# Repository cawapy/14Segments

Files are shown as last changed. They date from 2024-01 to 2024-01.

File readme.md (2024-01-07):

# Gallery

## Plain PCB

### Front

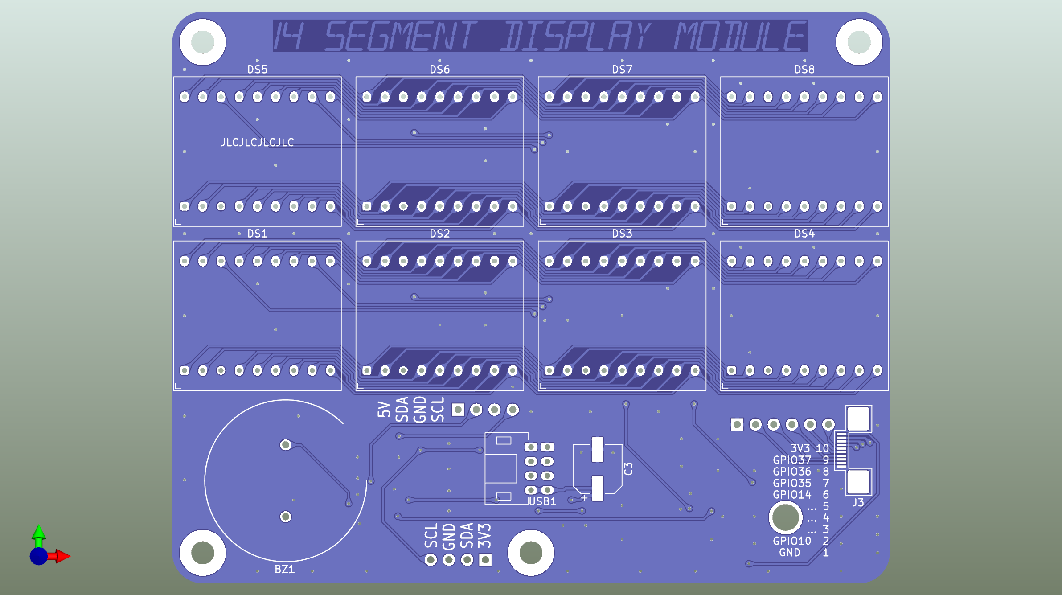
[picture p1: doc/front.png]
Front


### Back

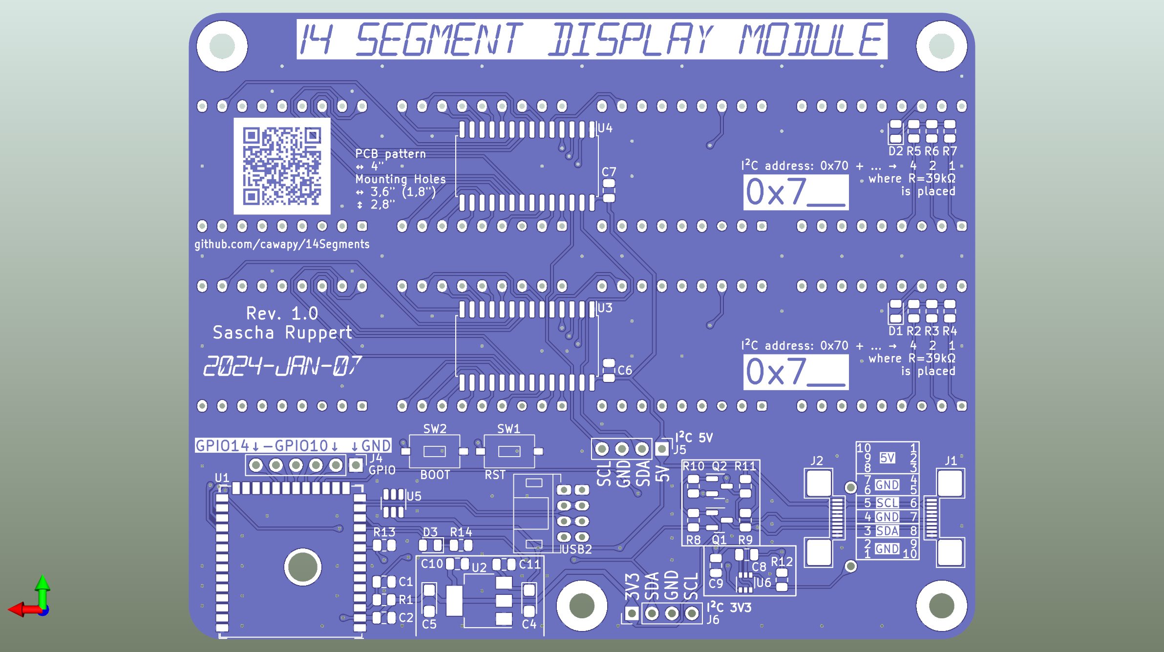
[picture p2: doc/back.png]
Back


## Master Board Assembly

### Front

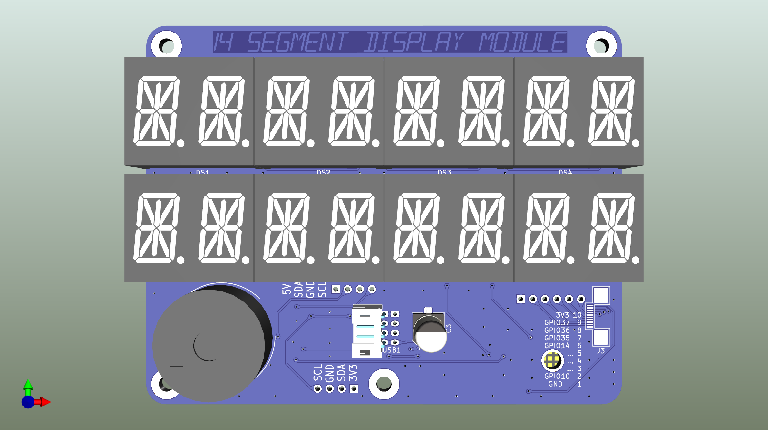
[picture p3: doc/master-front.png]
Front

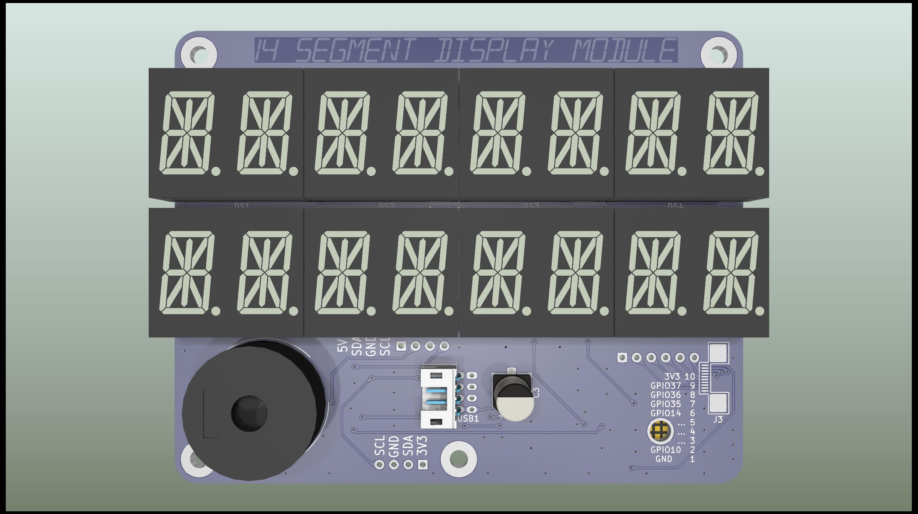
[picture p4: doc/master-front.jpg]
Front


### Back

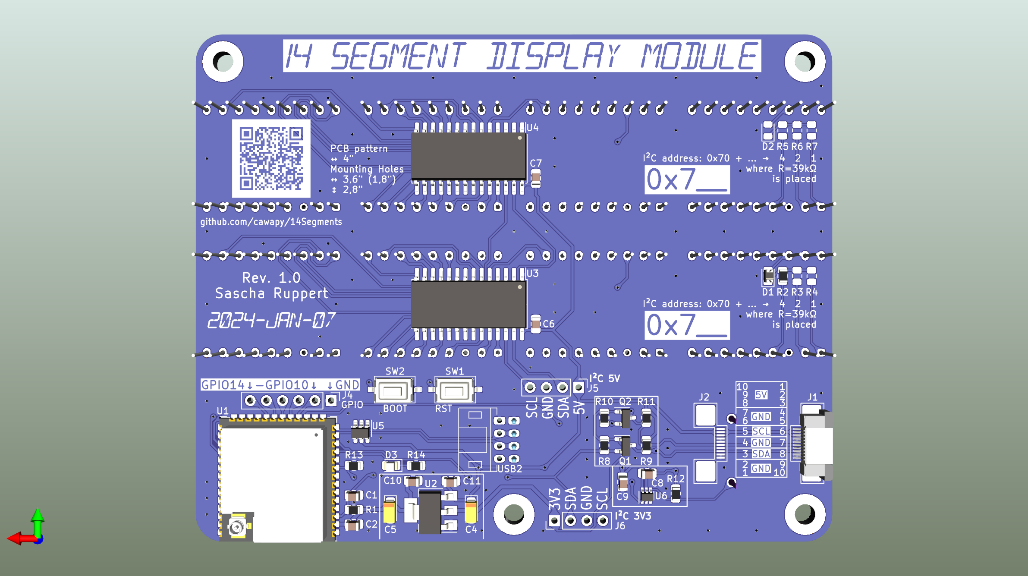
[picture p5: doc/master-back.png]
Back

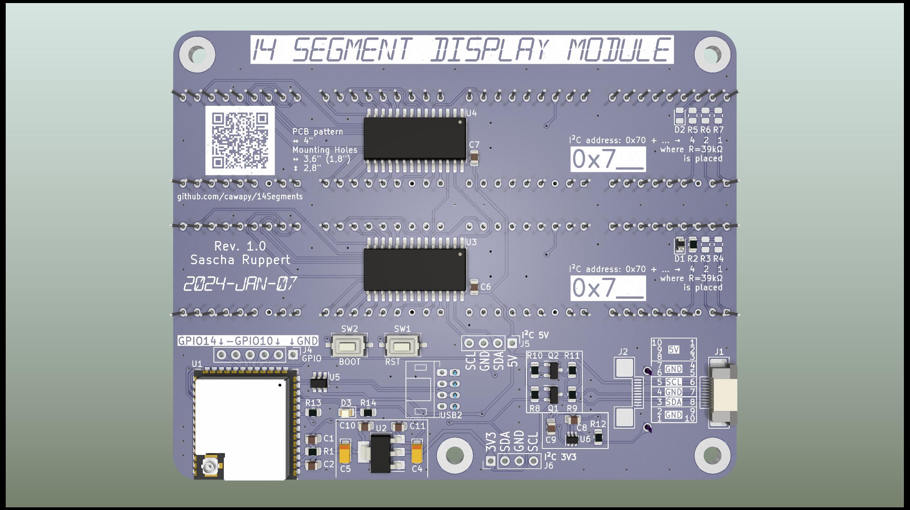
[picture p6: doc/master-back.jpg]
Back


## Slave Board Assembly

### Front

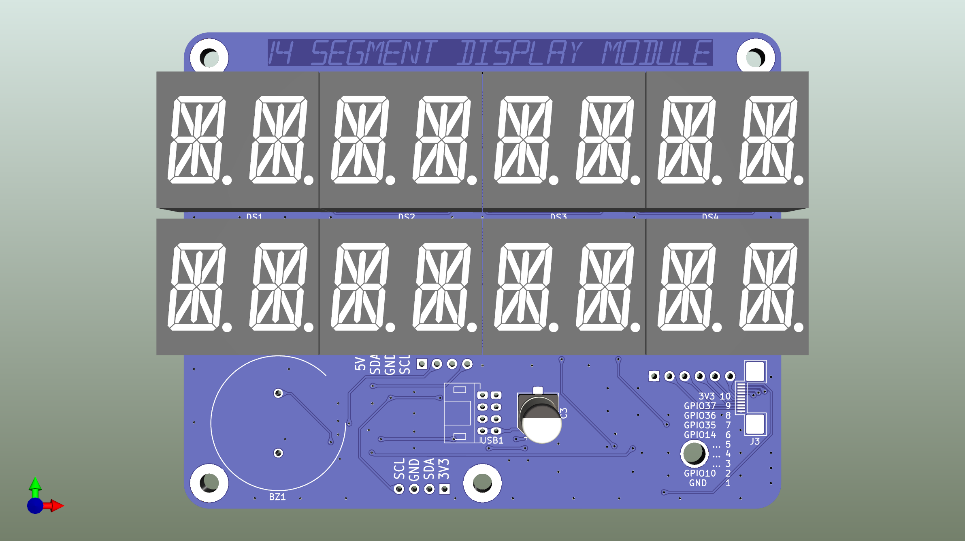
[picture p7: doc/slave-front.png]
Front

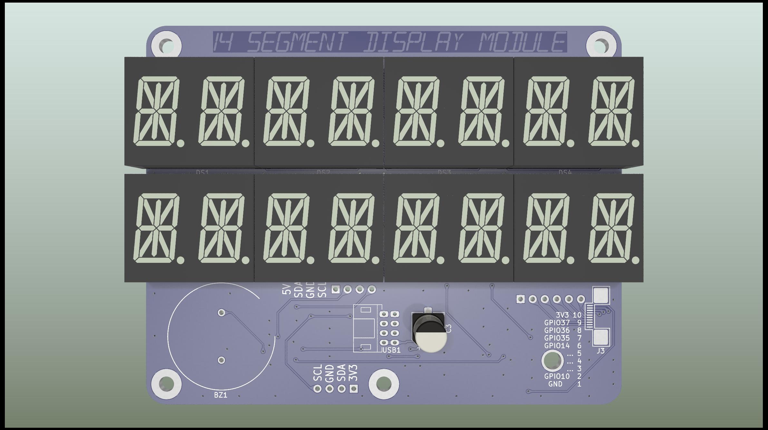
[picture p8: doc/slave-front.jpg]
Front


### Back

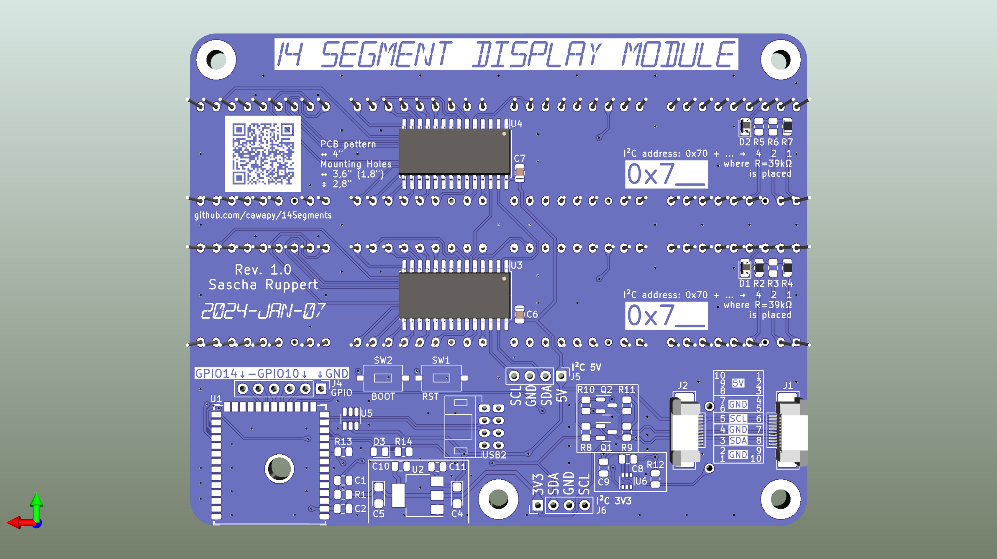
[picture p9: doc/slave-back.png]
Back

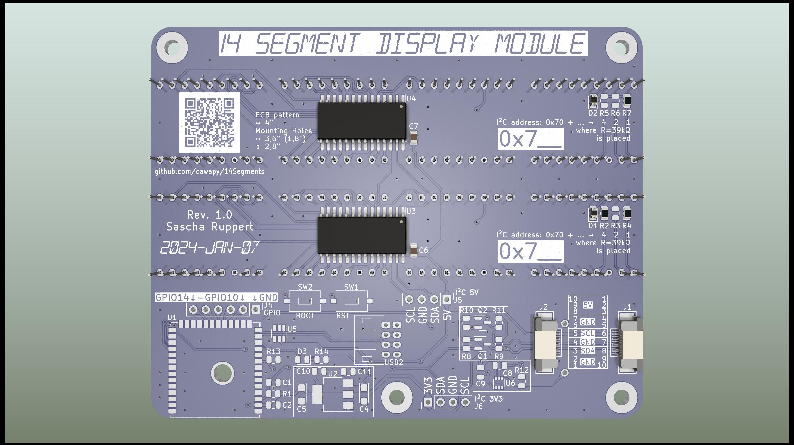
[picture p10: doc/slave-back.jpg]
Back


## Master + Slave Configuration

### Front

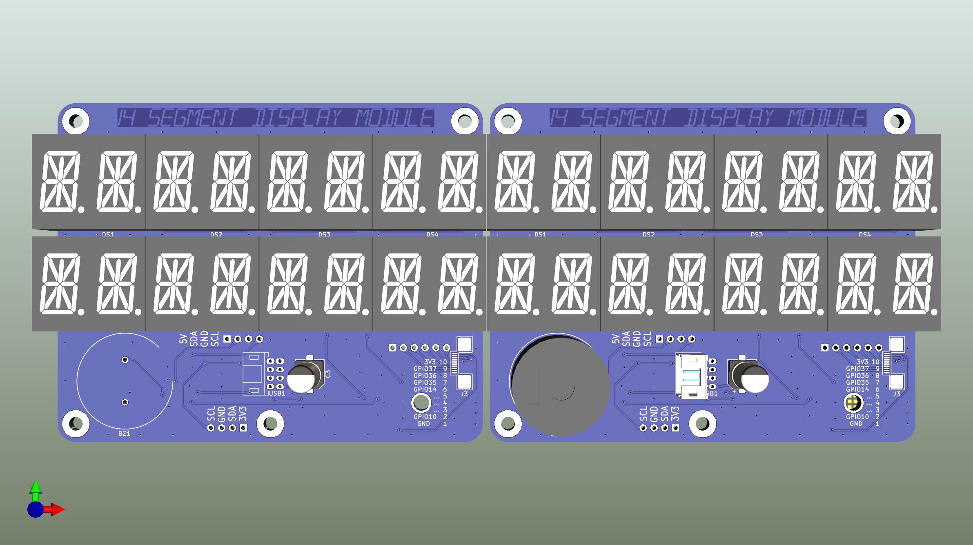
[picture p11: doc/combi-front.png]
Front

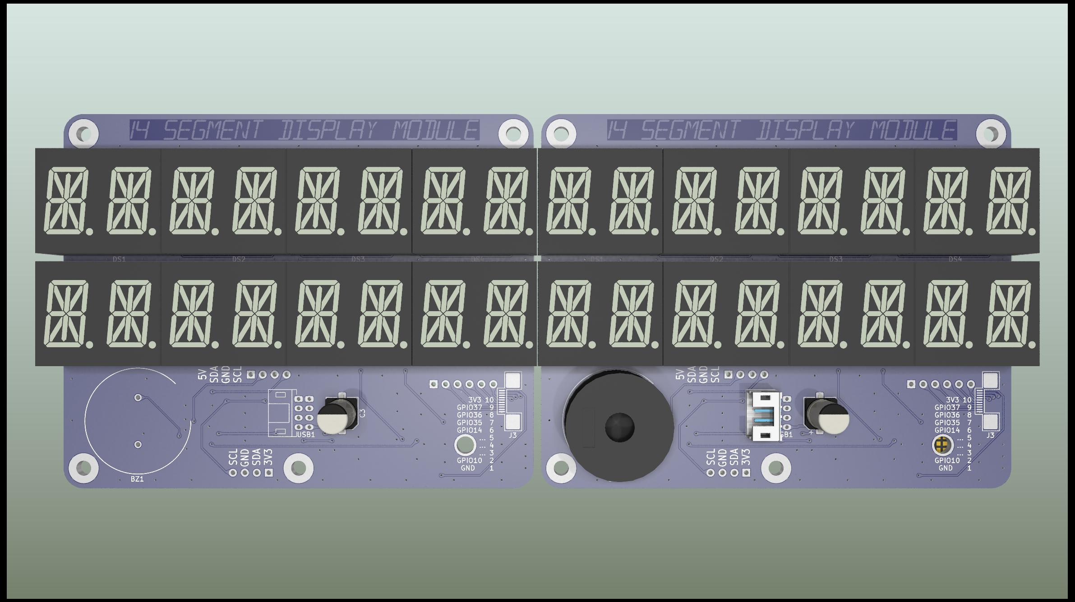
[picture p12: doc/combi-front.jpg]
Front


### Back

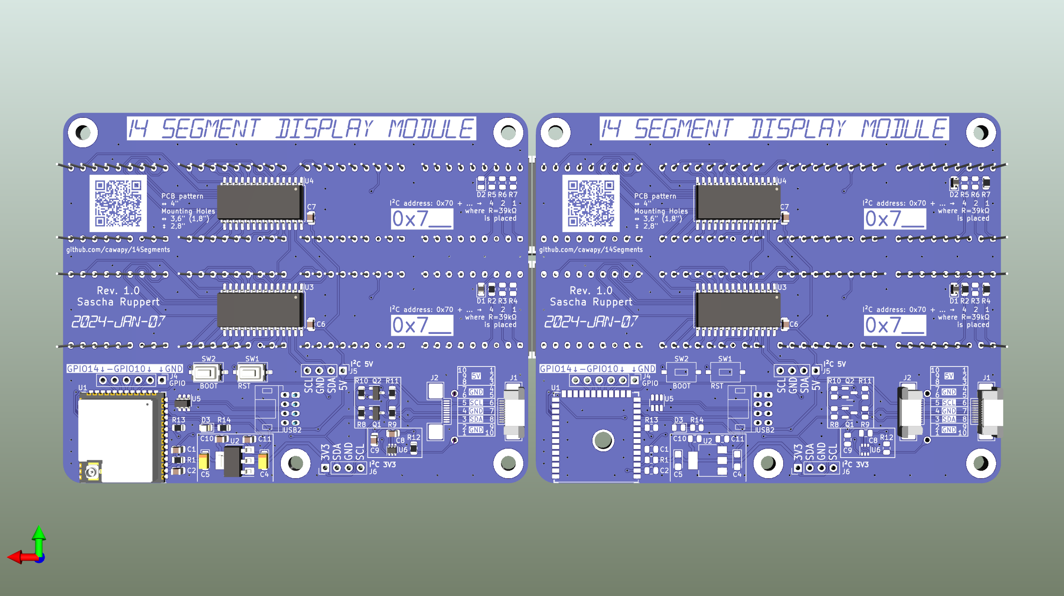
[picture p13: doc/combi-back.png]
Back

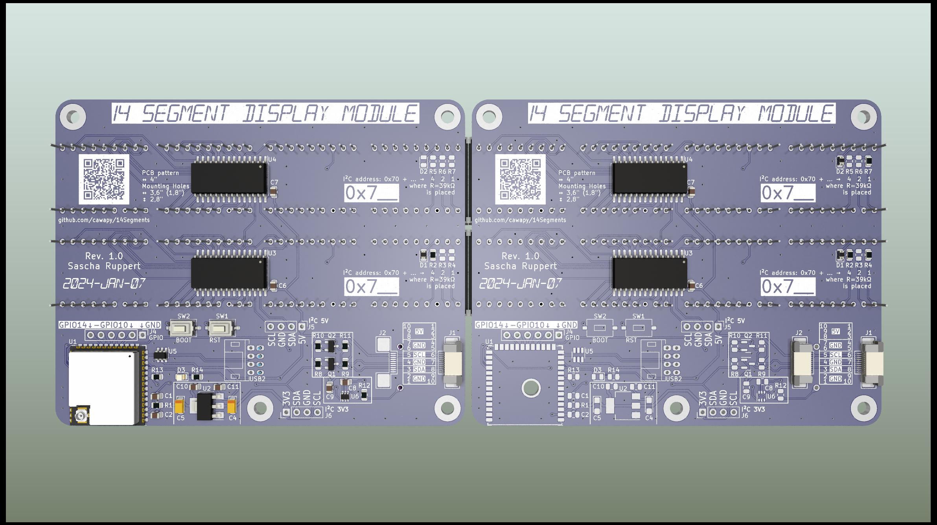
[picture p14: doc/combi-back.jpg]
Back


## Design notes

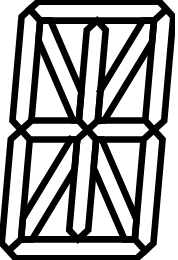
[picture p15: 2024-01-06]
14seg.png

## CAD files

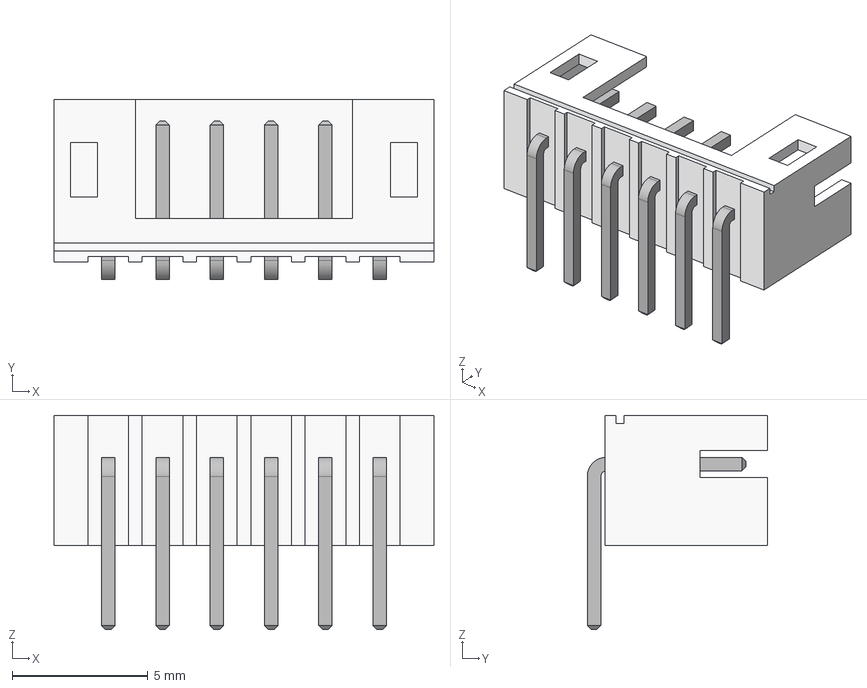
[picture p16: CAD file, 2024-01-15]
Connector4P.FCStd
14.0 x 6.65 x 7.90 mm
Housing
Pin1 x 6

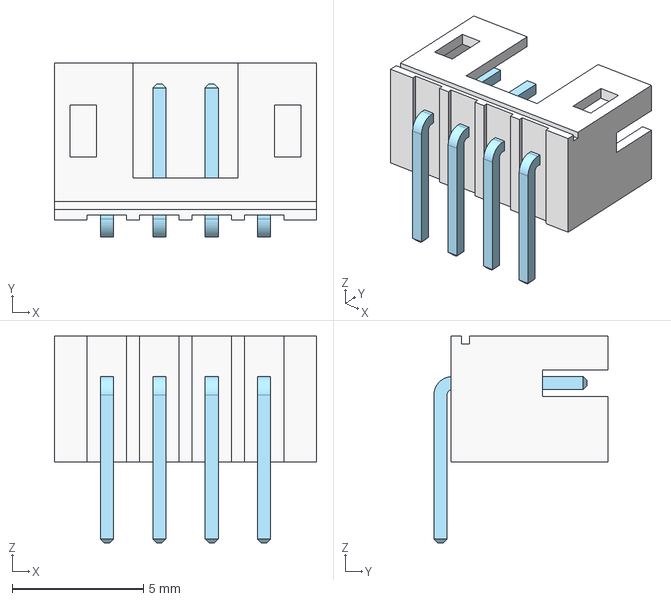
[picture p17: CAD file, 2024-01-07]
Connector4P-Connector P=2.0 4x.step
10.0 x 6.65 x 7.90 mm
Housing
Pin1 x 4

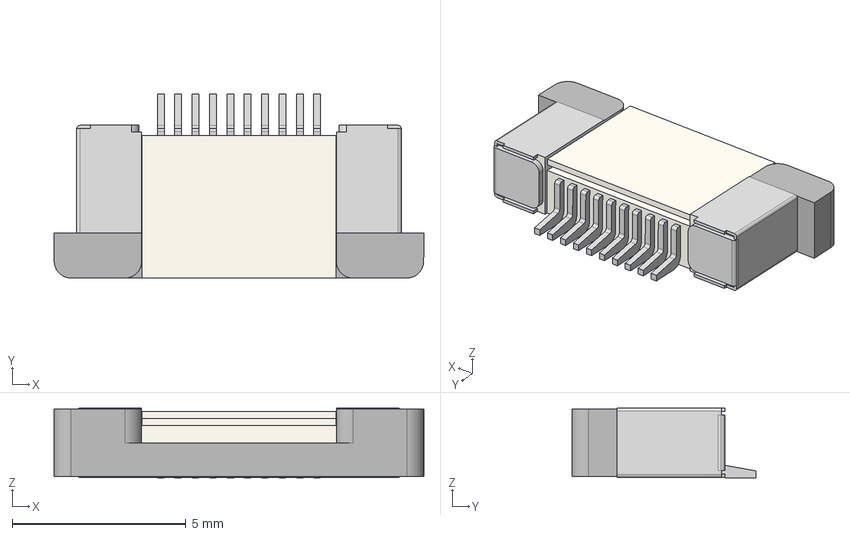
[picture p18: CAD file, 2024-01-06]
Connector10P-propper-size-2.step
10.7 x 5.30 x 2.01 mm

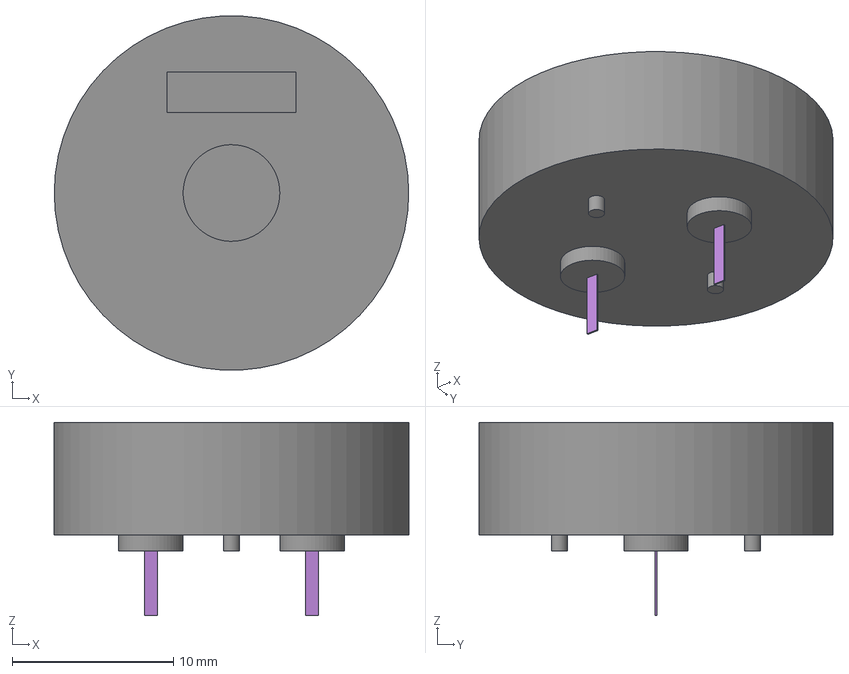
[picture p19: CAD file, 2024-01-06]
PiezoBuzzerAc2208.step
22.0 x 22.0 x 12.0 mm
PinBody x 2
HousingBody

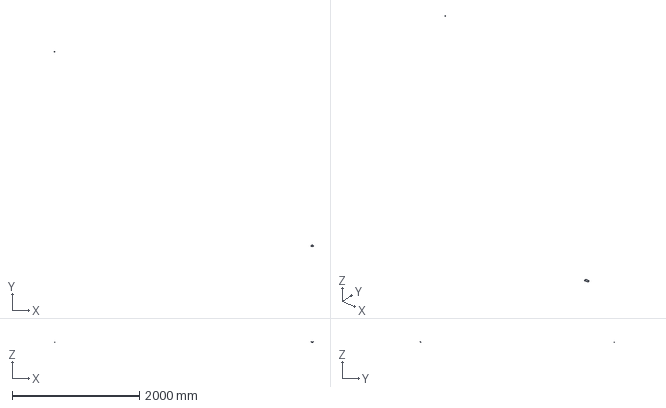
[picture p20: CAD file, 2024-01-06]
Connector10P.FCStd
4073.1 x 3065.8 x 7.91 mm

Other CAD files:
Connector6P-Connector P=2.0 6x.step

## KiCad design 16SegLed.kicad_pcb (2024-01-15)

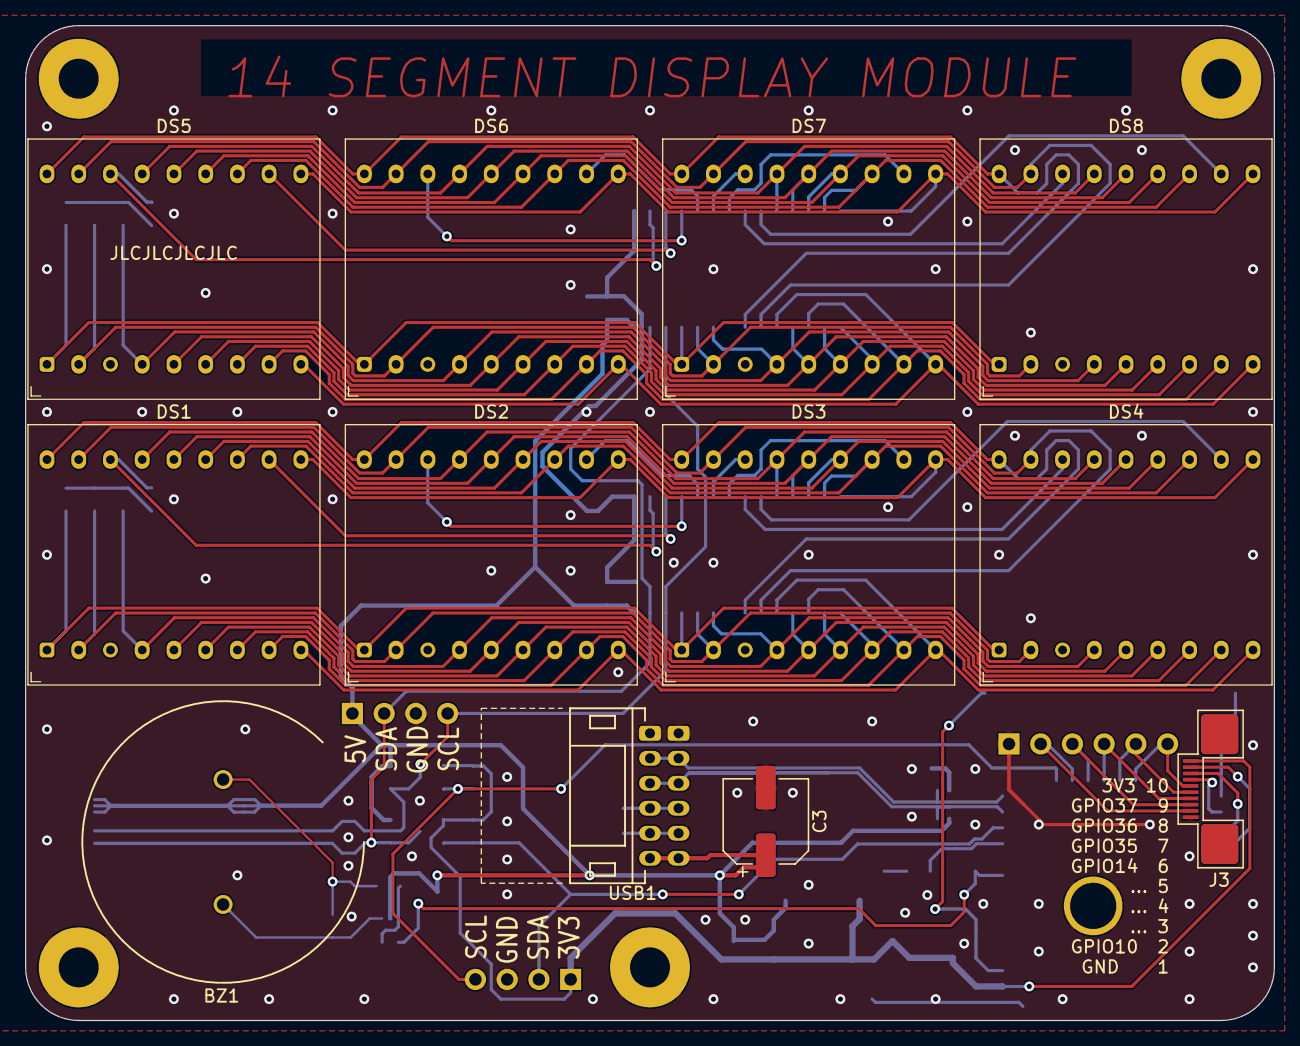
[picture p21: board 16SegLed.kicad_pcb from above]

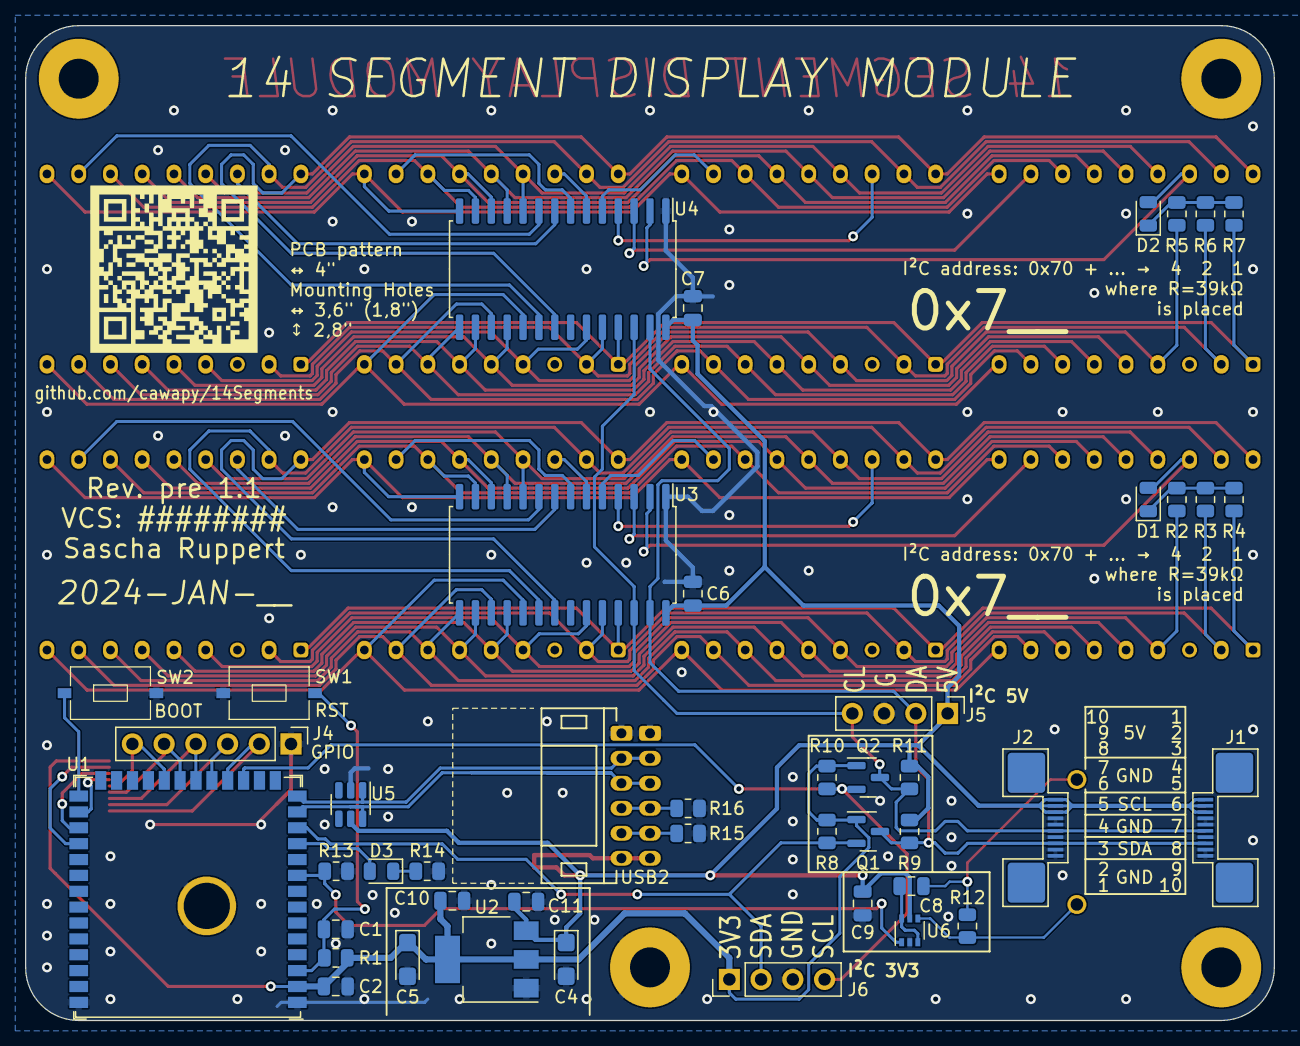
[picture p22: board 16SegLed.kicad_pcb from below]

Board: 2 copper layers, 99.9 x 79.6 mm, 62 parts (48 on the bottom side), 75 nets.

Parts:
BZ1: Buzzer; Buzzer-AC2208A
C1, C8, C9: 1µF; C_0805_2012Metric
C2, C6, C7, C10, C11: 100nF; C_0805_2012Metric
C3: 220µF; CP_Elec_6.3x7.7
C4: 10µF; CP_EIA-3216-10_Kemet-I
C5: 100µF; CP_EIA-3216-10_Kemet-I
D1, D2: LIZ Elec CD4148WSP; D_0805_2012Metric
D3: LED; LED_0805_2012Metric
DS1, DS2, DS3, DS4, DS5, DS6, DS7, DS8: 5241AX; DIP-18_600_ELL
FID1: Fiducial; QR-Code
H1, H2, H3, H4: MountingHole; MountingHole_3.2mm_M3_Pad
J1, J2, J3: Conn_01x10; FPC_10
J4: Conn_01x06_Socket; PinHeader_1x06_P2.54mm_Vertical
J5, J6: Conn_01x04_Pin; PinHeader_1x04_P2.54mm_Vertical
Q1, Q2: BSS138; SOT-23
R1, R8, R9, R10, R11, R13: 10kΩ; R_0805_2012Metric
R2, R3, R4, R5, R6, R7: 39kΩ; R_0805_2012Metric
R12: 1M; R_0805_2012Metric
R14: 220Ω; R_0805_2012Metric
R15, R16: 5.1kΩ; R_0805_2012Metric
SW1, SW2: SW_Push; Switch-Order-Ali-2023-12-14
U1: ESP32-S3-WROOM-1; ESP32-S3-WROOM-1U_THT-Pad
U2: AMS1117-3.3; SOT-223-3_TabPin2
U3, U4: HT16K33/28; SOIC-28W_7.5x17.9mm_P1.27mm
U5: SRV05-4; SOT-23-6
U6: 74LVC2G14; SOT-363_SC-70-6
USB1, USB2: HC-PH-6AW-G; PH 1x06 P2.0

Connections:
+3V3: C2.1, C5.1, C10.2, J3.10, J6.1, Q1.1 (G), Q2.1 (G), R1.1, R8.1, R10.1, U1.2 (3V3), U2.2 (VO)
+5V: C3.1, C4.1, C6.1, C7.1, C9.1, C11.2, J1.8, J1.9, J1.10, J2.1, J2.2, J2.3, J5.1, R9.1, R11.1, U2.3 (VI), U3.28 (VDD), U4.28 (VDD), U5.5 (VP), U6.5 (VCC), USB1.6, USB2.6
/BOOT: SW2.1, U1.27 (GPIO0/BOOT)
/BZ+: BZ1.1 (-), R12.1, U6.4
/BZ-: BZ1.2 (+), C8.2, R12.2
/CC1: R15.2, USB1.5, USB2.5
/CC2: R16.1, USB1.4, USB2.4
/CHIP_PU: C1.1, R1.2, SW1.2, U1.3 (EN)
/DisplayGroup0/CFG: D1.1 (K), R2.2, R3.2, R4.2
/DisplayGroup0/COM0: D1.2 (A), DS1.16 (CD1), U3.2 (COM0/AD)
/DisplayGroup0/COM1: DS1.11 (CD2), U3.3 (COM1/KS0)
/DisplayGroup0/COM2: DS2.16 (CD1), U3.4 (COM2/KS1)
/DisplayGroup0/COM3: DS2.11 (CD2), U3.5 (COM3/KS2)
/DisplayGroup0/COM4: DS3.16 (CD1), U3.6 (COM4)
/DisplayGroup0/COM5: DS3.11 (CD2), U3.7 (COM5)
/DisplayGroup0/COM6: DS4.16 (CD1), U3.8 (COM6)
/DisplayGroup0/COM7: DS4.11 (CD2), U3.9 (COM7)
/DisplayGroup0/SEG_{A}: DS1.12 (A), DS2.12 (A), DS3.12 (A), DS4.12 (A), U3.13 (ROW12/K10)
/DisplayGroup0/SEG_{B}: DS1.10 (B), DS2.10 (B), DS3.10 (B), DS4.10 (B), U3.14 (ROW11/K9)
/DisplayGroup0/SEG_{C}: DS1.9 (C), DS2.9 (C), DS3.9 (C), DS4.9 (C), U3.19 (ROW6/K4)
/DisplayGroup0/SEG_{D}: DS1.7 (D), DS2.7 (D), DS3.7 (D), DS4.7 (D), U3.15 (ROW10/K8)
/DisplayGroup0/SEG_{E}: DS1.1 (E), DS2.1 (E), DS3.1 (E), DS4.1 (E), R4.1, U3.25 (ROW0/A2)
/DisplayGroup0/SEG_{F}: DS1.18 (F), DS2.18 (F), DS3.18 (F), DS4.18 (F), U3.21 (ROW4/K2)
/DisplayGroup0/SEG_{G1}: DS1.13 (G1), DS2.13 (G1), DS3.13 (G1), DS4.13 (G1), U3.12 (ROW13/K11)
/DisplayGroup0/SEG_{G2}: DS1.6 (G2), DS2.6 (G2), DS3.6 (G2), DS4.6 (G2), U3.16 (ROW9/K7)
/DisplayGroup0/SEG_{H}: DS1.17 (H), DS2.17 (H), DS3.17 (H), DS4.17 (H), U3.20 (ROW5/K3)
/DisplayGroup0/SEG_{J}: DS1.15 (J), DS2.15 (J), DS3.15 (J), DS4.15 (J), U3.10 (ROW15/K13/INT)
/DisplayGroup0/SEG_{K}: DS1.14 (K), DS2.14 (K), DS3.14 (K), DS4.14 (K), U3.11 (ROW14/K12)
/DisplayGroup0/SEG_{L}: DS1.5 (L), DS2.5 (L), DS3.5 (L), DS4.5 (L), U3.18 (ROW7/K5)
/DisplayGroup0/SEG_{M}: DS1.4 (M), DS2.4 (M), DS3.4 (M), DS4.4 (M), R2.1, U3.23 (ROW2/A0)
/DisplayGroup0/SEG_{N}: DS1.2 (N), DS2.2 (N), DS3.2 (N), DS4.2 (N), R3.1, U3.24 (ROW1/A1)
/DisplayGroup0/SEG_{dp}: DS1.8 (DP), DS2.8 (DP), DS3.8 (DP), DS4.8 (DP), U3.17 (ROW8/K6)
/DisplayGroup1/CFG: D2.1 (K), R5.2, R6.2, R7.2
/DisplayGroup1/COM0: D2.2 (A), DS5.16 (CD1), U4.2 (COM0/AD)
/DisplayGroup1/COM1: DS5.11 (CD2), U4.3 (COM1/KS0)
/DisplayGroup1/COM2: DS6.16 (CD1), U4.4 (COM2/KS1)
/DisplayGroup1/COM3: DS6.11 (CD2), U4.5 (COM3/KS2)
/DisplayGroup1/COM4: DS7.16 (CD1), U4.6 (COM4)
/DisplayGroup1/COM5: DS7.11 (CD2), U4.7 (COM5)
/DisplayGroup1/COM6: DS8.16 (CD1), U4.8 (COM6)
/DisplayGroup1/COM7: DS8.11 (CD2), U4.9 (COM7)
/DisplayGroup1/SEG_{A}: DS5.12 (A), DS6.12 (A), DS7.12 (A), DS8.12 (A), U4.13 (ROW12/K10)
/DisplayGroup1/SEG_{B}: DS5.10 (B), DS6.10 (B), DS7.10 (B), DS8.10 (B), U4.14 (ROW11/K9)
/DisplayGroup1/SEG_{C}: DS5.9 (C), DS6.9 (C), DS7.9 (C), DS8.9 (C), U4.19 (ROW6/K4)
/DisplayGroup1/SEG_{D}: DS5.7 (D), DS6.7 (D), DS7.7 (D), DS8.7 (D), U4.15 (ROW10/K8)
/DisplayGroup1/SEG_{E}: DS5.1 (E), DS6.1 (E), DS7.1 (E), DS8.1 (E), R7.1, U4.25 (ROW0/A2)
/DisplayGroup1/SEG_{F}: DS5.18 (F), DS6.18 (F), DS7.18 (F), DS8.18 (F), U4.21 (ROW4/K2)
/DisplayGroup1/SEG_{G1}: DS5.13 (G1), DS6.13 (G1), DS7.13 (G1), DS8.13 (G1), U4.12 (ROW13/K11)
/DisplayGroup1/SEG_{G2}: DS5.6 (G2), DS6.6 (G2), DS7.6 (G2), DS8.6 (G2), U4.16 (ROW9/K7)
/DisplayGroup1/SEG_{H}: DS5.17 (H), DS6.17 (H), DS7.17 (H), DS8.17 (H), U4.20 (ROW5/K3)
/DisplayGroup1/SEG_{J}: DS5.15 (J), DS6.15 (J), DS7.15 (J), DS8.15 (J), U4.10 (ROW15/K13/INT)
/DisplayGroup1/SEG_{K}: DS5.14 (K), DS6.14 (K), DS7.14 (K), DS8.14 (K), U4.11 (ROW14/K12)
/DisplayGroup1/SEG_{L}: DS5.5 (L), DS6.5 (L), DS7.5 (L), DS8.5 (L), U4.18 (ROW7/K5)
/DisplayGroup1/SEG_{M}: DS5.4 (M), DS6.4 (M), DS7.4 (M), DS8.4 (M), R5.1, U4.23 (ROW2/A0)
/DisplayGroup1/SEG_{N}: DS5.2 (N), DS6.2 (N), DS7.2 (N), DS8.2 (N), R6.1, U4.24 (ROW1/A1)
/DisplayGroup1/SEG_{dp}: DS5.8 (DP), DS6.8 (DP), DS7.8 (DP), DS8.8 (DP), U4.17 (ROW8/K6)
/IO10: J3.2, J4.2, U1.18 (GPIO10/TOUCH10/ADC1_CH9/FSPICS0/FSPIIO4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)
/IO11: J3.3, J4.3, U1.19 (GPIO11/TOUCH11/ADC2_CH0/FSPID/FSPIIO5/S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)
/IO12: J3.4, J4.4, U1.20 (GPIO12/TOUCH12/ADC2_CH1/FSPICLK/FSPIIO6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)
/IO13: J3.5, J4.5, U1.21 (GPIO13/TOUCH13/ADC2_CH2/FSPIQ/FSPIIO7/S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)
/IO14: J3.6, J4.6, U1.22 (GPIO14/TOUCH14/ADC2_CH3/FSPIWP/FSPIDQS/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)
/IO35: J3.7, U1.28 (SPIIO6/GPIO35/FSPID/SUBSPID)
/IO36: J3.8, U1.29 (SPIIO7/GPIO36/FSPICLK/SUBSPICLK)
/IO37: J3.9, U1.30 (SPIDQS/GPIO37/FSPIQ/SUBSPIQ)
/LED: D3.2 (A), U1.11 (GPIO18/U1RXD/ADC2_CH7/CLK_OUT3)
/SCL3V3: J6.4, Q2.2 (S), R10.2, U1.17 (GPIO9/TOUCH9/ADC1_CH8/FSPIHD/SUBSPIHD)
/SCL5V: J1.5, J2.6, J5.4, Q2.3 (D), R11.2, U3.26 (SCL), U4.26 (SCL)
/SDA3V3: J6.2, Q1.2 (S), R8.2, U1.12 (GPIO8/TOUCH8/ADC1_CH7/SUBSPICS1)
/SDA5V: J1.3, J2.8, J5.2, Q1.3 (D), R9.2, U3.27 (SDA), U4.27 (SDA)
/SND: R13.1, U1.9 (GPIO16/U0CTS/ADC2_CH5/XTAL_32K_N), U6.1
/USB_D_MINUS: U1.13 (GPIO19/U1RTS/ADC2_CH8/CLK_OUT2/USB_D-), U5.6 (IO4), USB1.3, USB2.3
/USB_D_PLUS: U1.14 (GPIO20/U1CTS/ADC2_CH9/CLK_OUT1/USB_D+), U5.1 (IO1), USB1.2, USB2.2
/~SND: C8.1, U6.3, U6.6
GND: C1.2, C2.2, C3.2, C4.2, C5.2, C6.2, C7.2, C9.2, C10.1, C11.1, H1.1, H2.1, H3.1, H4.1, J1.1, J1.2, J1.4, J1.6, J1.7, J2.4, J2.5, J2.7, J2.9, J2.10, J3.1, J4.1, J5.3, J6.3, R13.2, R14.2, R15.1, R16.2, SW1.1, SW2.2, U1.1 (GND), U1.40 (GND), U1.41 (GND), U2.1 (GND), U3.1 (VSS), U4.1 (VSS), U5.2 (VN), U6.2 (GND), USB1.1, USB2.1
unnamed: D3.1 (K), R14.1

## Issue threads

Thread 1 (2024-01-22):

Disturbing noise on buzzer depending on LED pattern

cawapy, 2024-01-22:
There is unwanted noise comming from the buzzer unless LEDs are off entirely.
Depending on LED pattern shown, noise is more more or less intense.
While it is way quieter than the buzzer's beep, the noise is unpleasant.

cawapy, 2024-01-22:
This is from the 5V voltage dropping by up to approx. 200 mV while the display controller/driver is multiplexing a digit with high number of segments lit.

2 cascaded inverters are used to drive the 2 buzzer lines from 1 sound signal created by the ESP32. The outputs of the inverters correspond to GND and 5V rails respectively. The buzzer "sees" 5V or -5V, which contains the ripple caused by the display controller/drivers which translates to noise directly.

This is a design flaw.

Options:
* Drive second inverter by another signal provided by the ESP. Then the software on ESP could make sure both buzzer lines see the same level when not playing any sound.
* Bind one of the buzzer lines to GND. Again, the software on ESP could then make sure the other line will be driven to same voltage when not playing any sound.
* Stabilize supply voltage of inverter

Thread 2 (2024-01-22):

Wrong explanation of I2C address setup on silkscreen

cawapy, 2024-01-22:
On back silkscreen, there is text "I2C address: 0x70 + ... 4 2 1 where R=39k... ", with the numbers 4, 2 and 1 corresponding to R2, R3, R4 and R5, R6, R7.

But the assignment is wrong. R2 and R5 do not shift the address by 4 but by 1, and R4 and R7 shift it by 1 and not 4.

cawapy, 2024-01-22:
Assignment of address resistors is wrong. It was assumed that on HT16K33/28, ROW0 corresponds A0 and ROW2 to A2, but the 3 address inputs and the row outputs are assigned to pins in opposite direction.

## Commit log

2024-01-06 Flipped all SMD components to back side
    - Exceptions: large electrolytic capacitor, optional GPIO connector
    [16SegLed.kicad_pcb]
2024-01-06 Add QR code for repository @ github
    [16SegLed.kicad_pcb, 16SegLed.kicad_sch]
2024-01-06 Add teardrops
    [16SegLed.kicad_pcb]
2024-01-06 Cleaning up Fab layers
    [16SegLed.kicad_pcb]
2024-01-06 Use meaningful segment net names
    [16SegLed.kicad_pcb, DisplayGroup.kicad_sch]
2024-01-06 Ignore Kicad lock files
2024-01-06 Rearrange ROW assignment so digits are scanned consecutively from left to right
    [16SegLed.kicad_pcb, DisplayGroup.kicad_sch]
2024-01-06 Improve routing of power and I2C nets for LED drivers
    [16SegLed.kicad_pcb]
2024-01-07 Rearrange GND vias
    [16SegLed.kicad_pcb]
2024-01-07 Connect mounting holes to ground
    [16SegLed.kicad_pcb, 16SegLed.kicad_sch]
2024-01-07 Enlarge FPC connector mounting pads to enable hand soldering
    [16SegLed.kicad_pcb]
2024-01-07 Fix 3.3 V regulator circuit
    - Use polarized footprints for tantalum capacitors
    - Add 100nF at input and output of AMS1117
    [16SegLed.kicad_pcb, 16SegLed.kicad_sch]
2024-01-07 Add boxes to component groups on silkscreen
    - including rearrangement of piezo buzzer's discharge resistor closer to other parts of that group
    [16SegLed.kicad_pcb]
2024-01-07 Rearrange I2C 3V3 testconnector into less crowded area on PCB
    [16SegLed.kicad_pcb]
2024-01-07 Update USB connectors to be able to move I2C 5V test connector to less crowded place
    - using 2 of them (support installation on front and back in parallel in case needed differently in application than in prototype)
    - using own footprint, matching LCSC part C5342444
    - including own 3d model
    [16SegLed.kicad_pcb, 16SegLed.kicad_sch, Connector4P-Connector P=2.0 4x.step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]
2024-01-07 Reset usage of flag "do not place"
    [16SegLed.kicad_pcb, 16SegLed.kicad_sch, DisplayGroup.kicad_sch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]
2024-01-07 Include teardrops for through-hole pads
    [16SegLed.kicad_pcb]
2024-01-07 Include readme with some sample pictures
2024-01-07 Include commit hash on PCB for first revision
    [16SegLed.kicad_pcb]
2024-01-07 Add Gerber files for 1.0
    [16SegLed-B_Cu.gbr, 16SegLed-B_Mask.gbr, 16SegLed-B_Paste.gbr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]
2024-01-14 Add comment on wall/panel mount USB-C socket
    [16SegLed.kicad_sch]
2024-01-15 Support native USB-C
    - use 6P terminal for wall mount USB-C socket
    - include 2x 5k1 resistors for CC1 and CC2
    - larger footprints of connectors require partial re-layout
    [16SegLed.kicad_pcb, 16SegLed.kicad_sch, Connector4P.FCStd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]
